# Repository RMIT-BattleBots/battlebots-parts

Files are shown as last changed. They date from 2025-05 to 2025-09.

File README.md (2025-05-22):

# BattleBots Club – 3D Printed Components Repository

Welcome to the official 3D components repository for the **RMIT BattleBots Club**! This repository contains all the STL, STEP, and source design files used in the construction and development of our robots' 3D printed parts.

## Repository Structure

```
battlebots-parts/
├── README.md
│
├── robot1_components/
│ ├── drivetrain/
│ │ ├── motor_mount.stl
│ │ ├── motor_mount.step
│ │ └── README.md
│ │
│ ├── armor/
│ │ ├── front_plate_v1.stl
│ │ ├── front_plate_v2.stl
│ │ ├── front_plate_v3.stl
│ │ ├── front_plate_v4.stl
│ │ ├── front_plate_v4.step
│ │ └── README.md
│ │
│ ├── mounts/
│ │ ├── esc_holder
│ │ │ ├── esc_holder.stl
│ │ │ └── escHolder.png
│
├── robot2_components/
│ ├── drivetrain/
│ │ ├── motor_mount.stl
│ │ ├── motor_mount.step
│ │ └── README.md
```

Each folder contains:

- `.stl` files – ready to slice and print
- `.step` or native CAD files – for easy modifications
- `.png` for images of the part, either the 3d model or the part implemented onto the part (make filename oneword please)
- A README describing how and where the part is used, settings used for printing and the image embed

## Contributing

We encourage club members to contribute their designs and improvements! please checkout `CONTRIBUTING.md`

Please ensure you have the right to share any files uploaded, especially if they are used for competition bots.

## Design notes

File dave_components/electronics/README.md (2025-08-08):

# Electronics

Folder contains electronics parts for Dave.

## Part(s) locations
The motor PCBs are located on the motors, where the motor pins are slotted and soldered into the two larger offset pin through holes in the PCB. 

## Version 2 Notes
 - Motor PCB is to allow for strong and compact perpindicular electrical connections within the robot housing.
     - Track width is 2.0mm which is more than enough for a 1-  2Amps
 - Overall profile is smaller, with larger holes
 - Made in KiCad

## Version 1 Notes 
 - Motor PCB is to allow for strong and compact perpindicular electrical connections within the robot housing.
     - Track width is like 2 or 1.5mm which is more than enough for a 1-2Amps
     - The lower 4 through holes which are compatible with JST XH A connectors (standard 2.5mm spacing) 
 - Made in KiCad

## Images

Current components:

#### Version 2

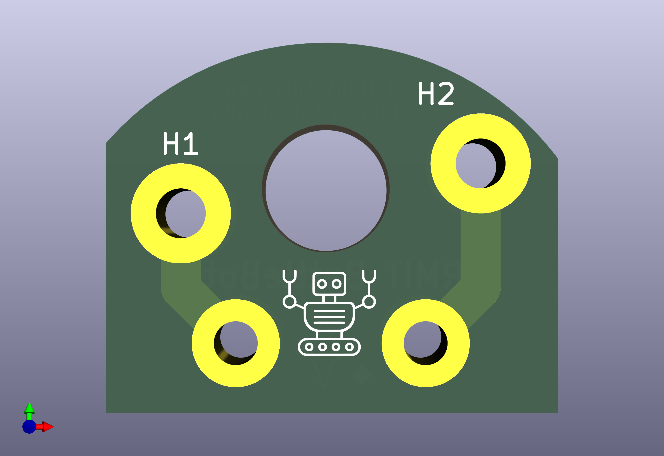
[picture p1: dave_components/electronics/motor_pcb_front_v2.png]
3D model top view of PCB


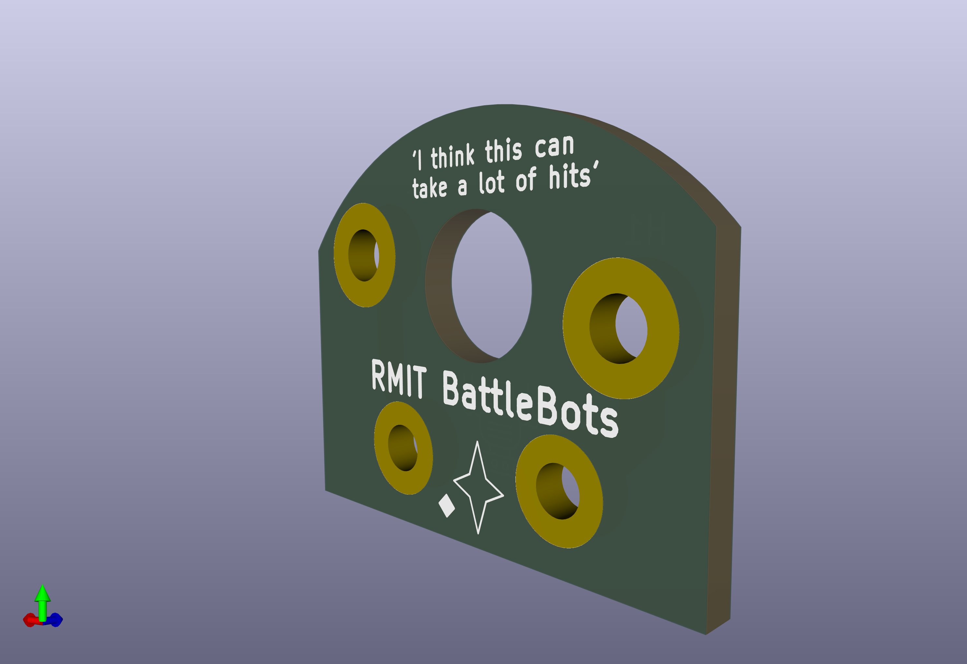
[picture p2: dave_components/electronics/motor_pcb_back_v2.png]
3D model back angled view of PCB


#### Version 1

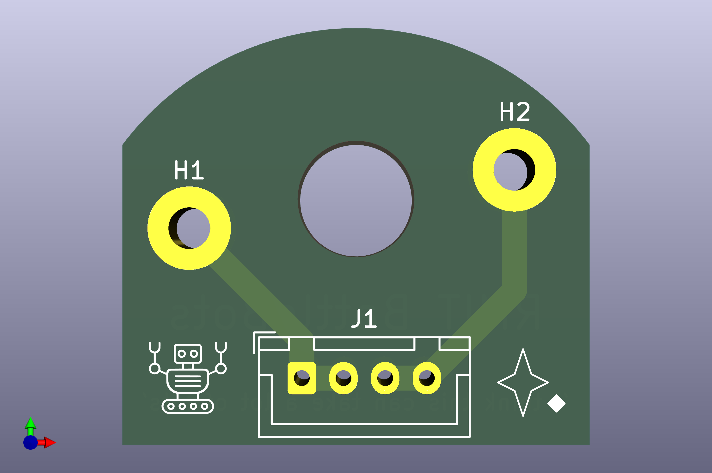
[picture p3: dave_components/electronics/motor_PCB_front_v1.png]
3D model top view of PCB 3D model top view of old PCB


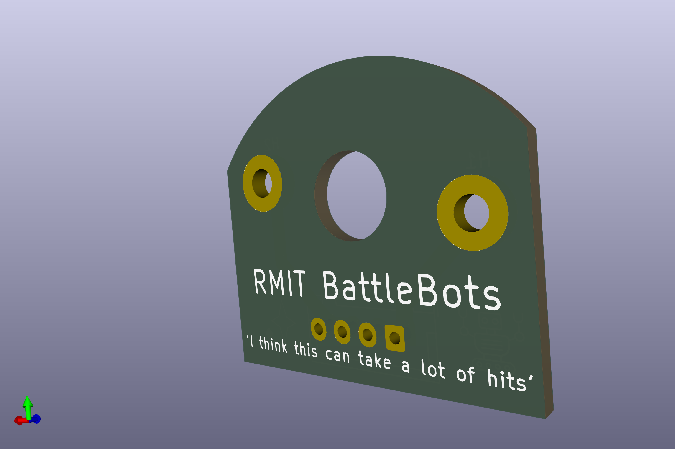
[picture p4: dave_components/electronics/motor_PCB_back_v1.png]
3D model back angled view of PCB 3D model back angled view of old PCB


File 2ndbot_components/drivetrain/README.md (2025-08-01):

# Drivetrain

Any and all parts related to the 2nd Bot drivetrain.

## Parts locations

The wheels are located to either side of the robot.

The motor brackets are connected to the base plate of the bot

## settings used for printing

- 30% infil
- default profile (0.2mm)

## Images

Current components:

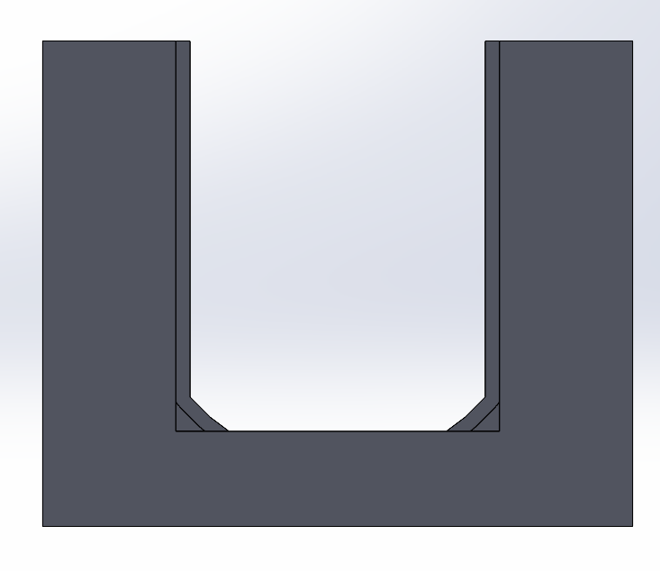
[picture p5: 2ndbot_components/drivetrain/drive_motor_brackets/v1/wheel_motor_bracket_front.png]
3D model of wheel motor bracket (front view)


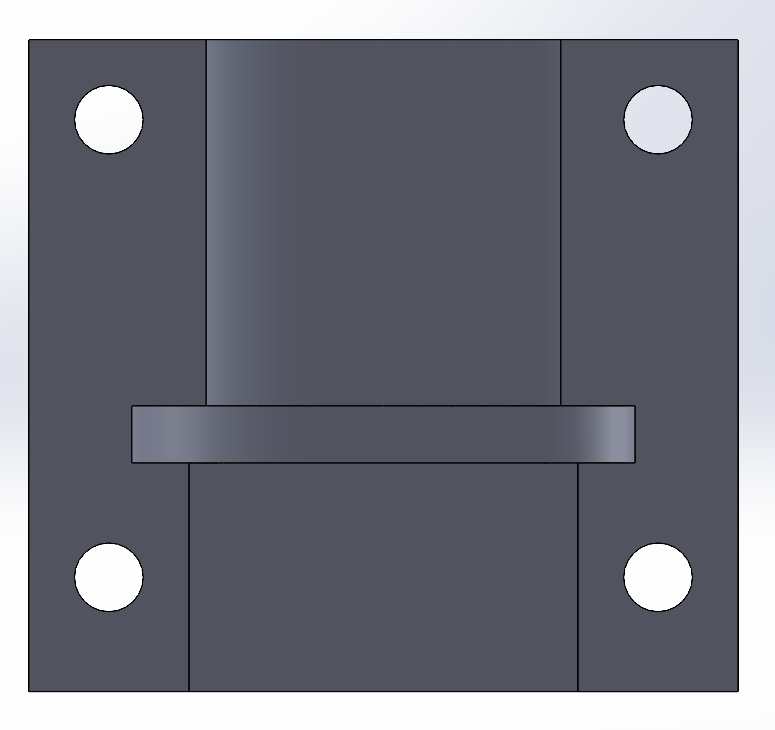
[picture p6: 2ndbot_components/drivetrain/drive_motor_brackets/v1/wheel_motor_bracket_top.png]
3D model of wheel motor bracket (top view)


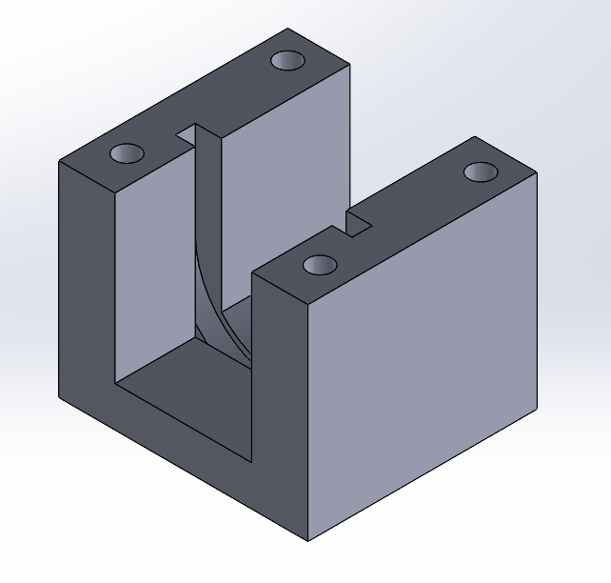
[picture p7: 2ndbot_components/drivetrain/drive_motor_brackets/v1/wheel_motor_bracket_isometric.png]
3D model of wheel motor bracket (isometric view)


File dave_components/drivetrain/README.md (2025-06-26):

# Drivetrain

Any and all parts related to the Dave drivetrain.

## Parts locations

The wheels are located to either side of the robot.

The motor brackets are located inside the robot housing adjacent to the wheels to hold the motors up. Version two has the mounts attach to the walls of the robot, whereas version one has a single pillar mounting to the floor of the robot

## settings used for printing

- 30% infil
- default profile (0.2mm)

## Images

Current components:

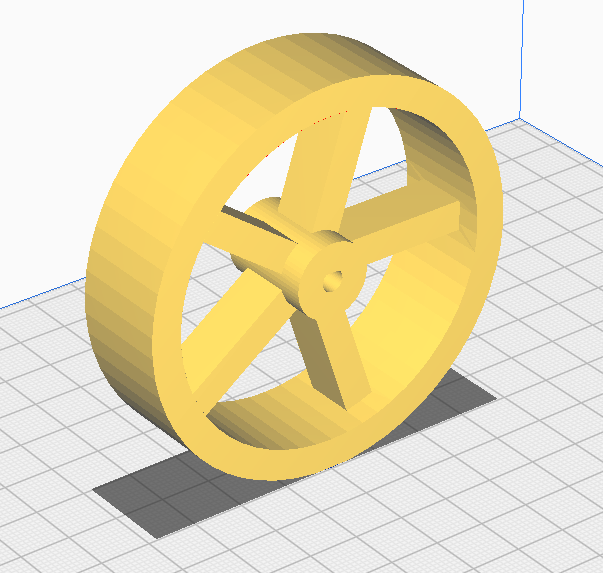
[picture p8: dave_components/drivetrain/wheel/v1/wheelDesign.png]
3D model of wheel design


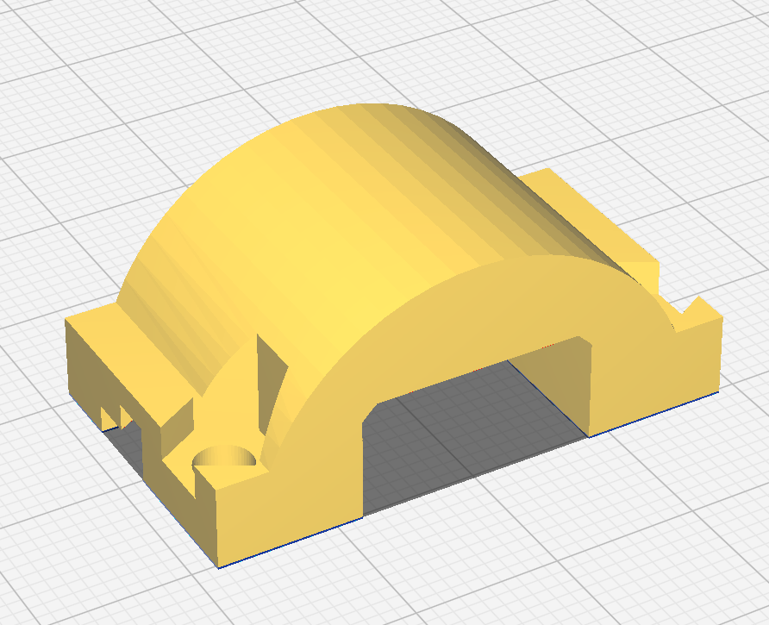
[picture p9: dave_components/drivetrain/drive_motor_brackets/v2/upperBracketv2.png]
3D model of upper bracket design


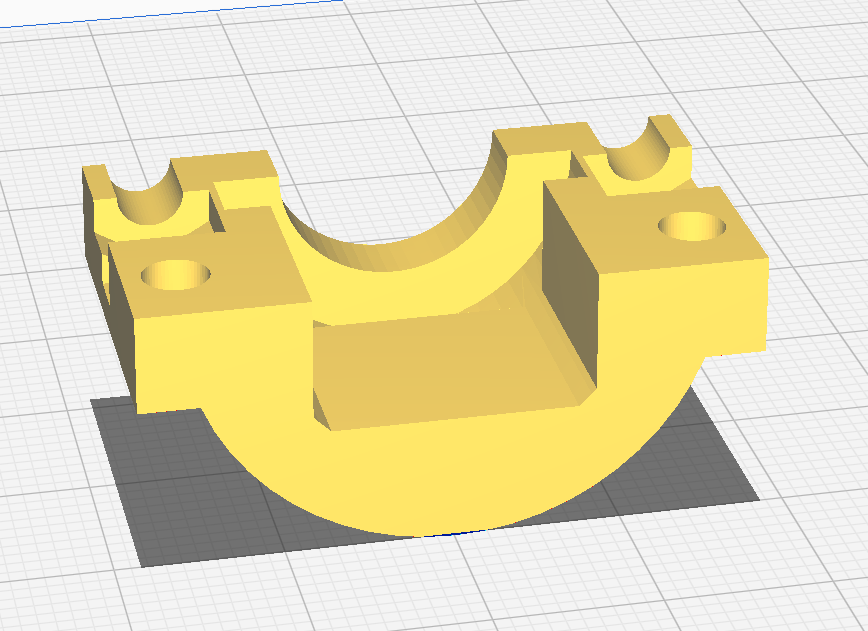
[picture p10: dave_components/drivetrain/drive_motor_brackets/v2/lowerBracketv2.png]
3D model of lower bracket design


Outdated/used prior:

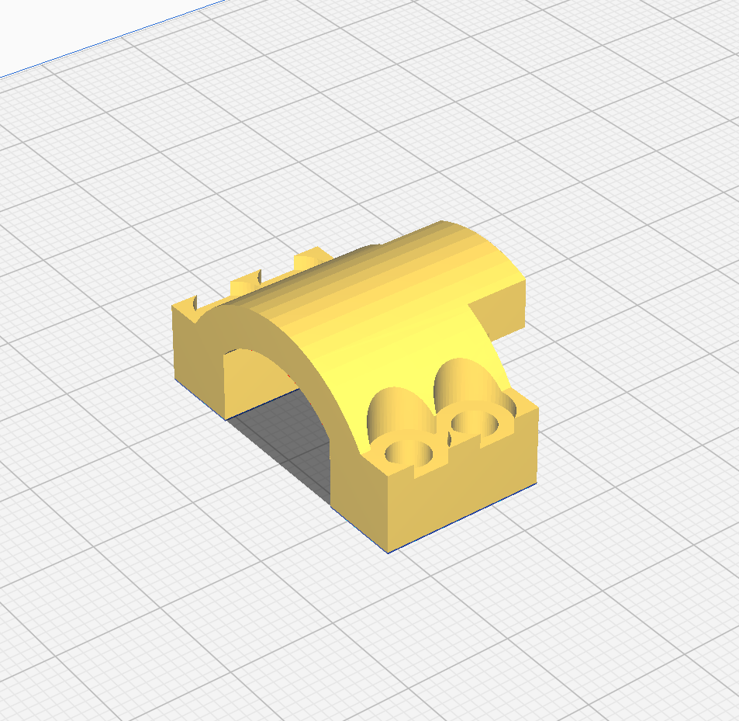
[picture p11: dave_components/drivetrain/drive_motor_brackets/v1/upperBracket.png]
3D model of old upper bracket design


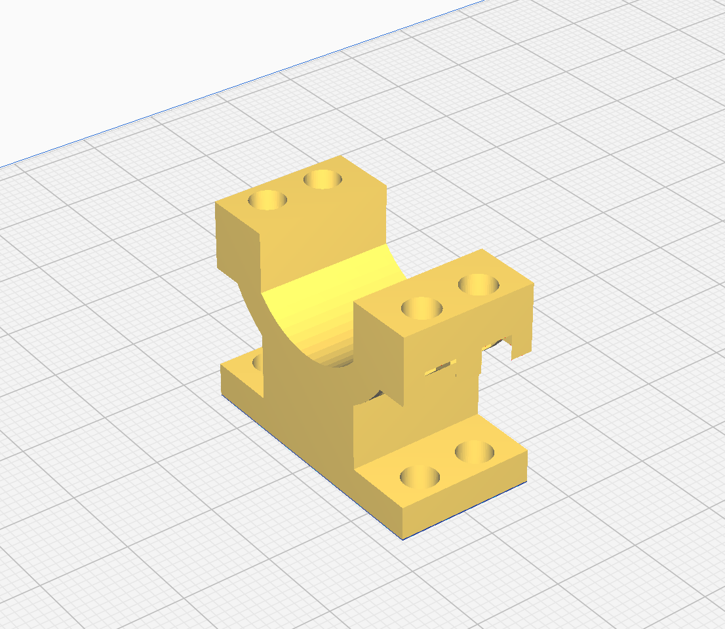
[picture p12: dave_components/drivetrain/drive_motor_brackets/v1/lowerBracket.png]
3D model of old lower bracket design


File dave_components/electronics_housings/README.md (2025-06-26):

# Electronics Housing

Any and all parts related to mounting electronics for Dave.

## Parts locations

The switch housing is located inside the housing towards the top side of the robot.

## settings used for printing

Infill negligible as the part is small enough to be mostly wall layers

## Images

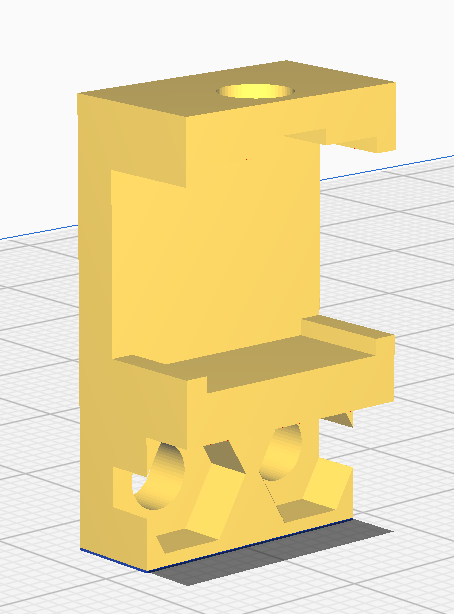
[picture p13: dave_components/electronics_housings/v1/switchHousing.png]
3D model of switch housing design


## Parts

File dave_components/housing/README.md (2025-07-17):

# Housing

Any and all parts related to the Dave housing/armour.

## Parts locations

The bracket is located in 4 instances, and uses bolts to fasten the side walls, roof and floor of the robot at each corner.

## settings used for printing

(?)

## Images

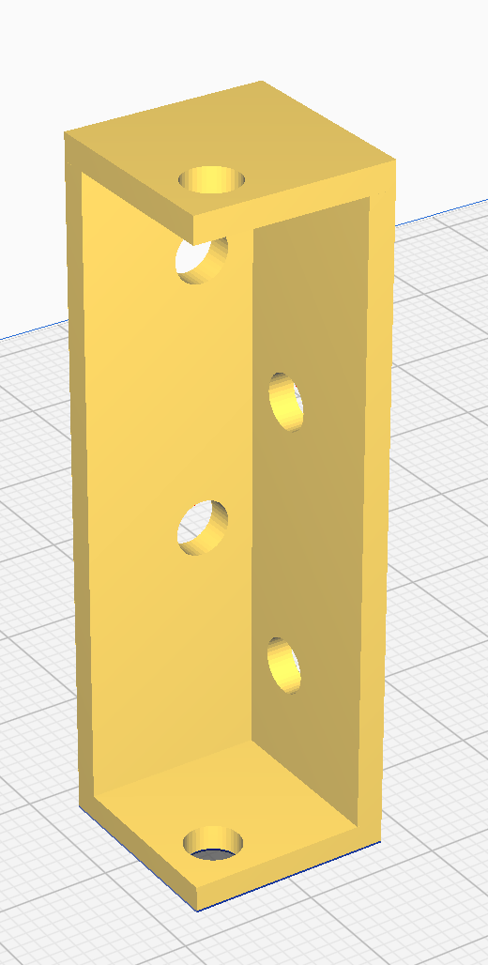
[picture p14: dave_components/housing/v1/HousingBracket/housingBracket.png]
3D model of housing bracket design


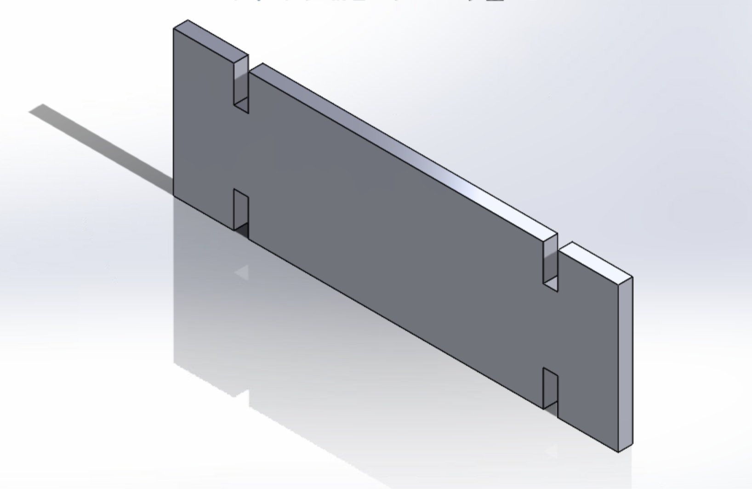
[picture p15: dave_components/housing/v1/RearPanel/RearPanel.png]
3D model of rear panel design


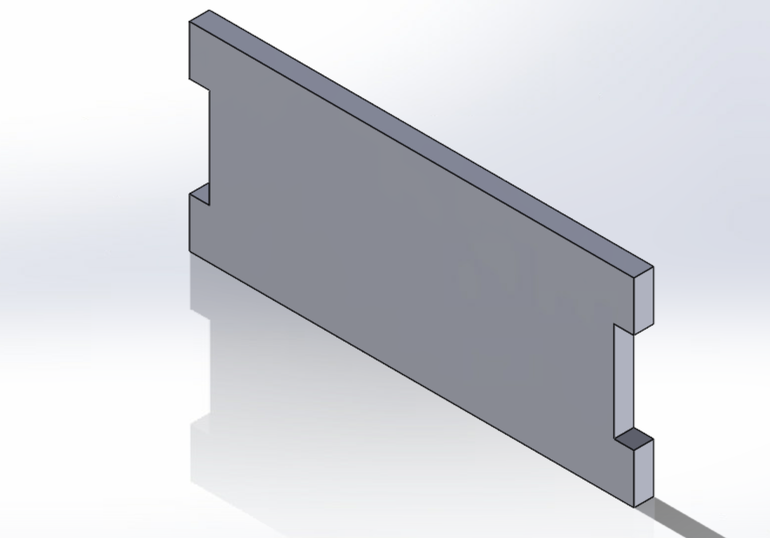
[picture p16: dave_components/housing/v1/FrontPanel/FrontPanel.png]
3D model of front panel design


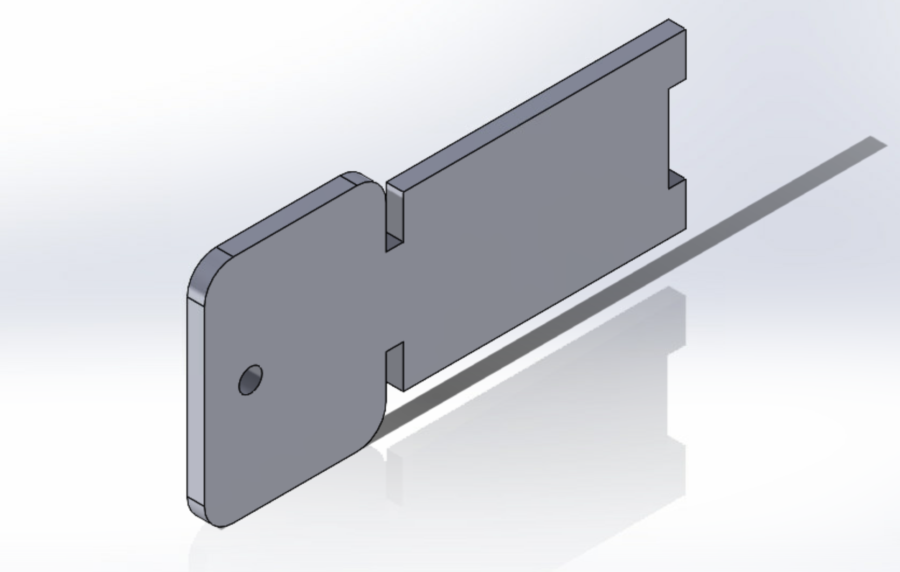
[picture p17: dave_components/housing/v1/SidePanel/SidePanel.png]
3D model of side panel design


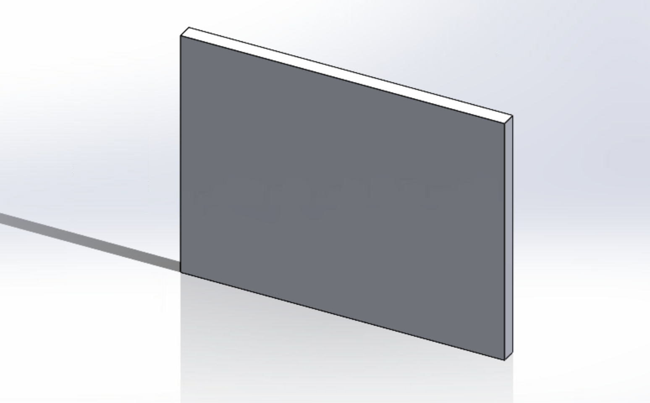
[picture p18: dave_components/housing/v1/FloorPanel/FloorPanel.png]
3D model of floor and roof panel design


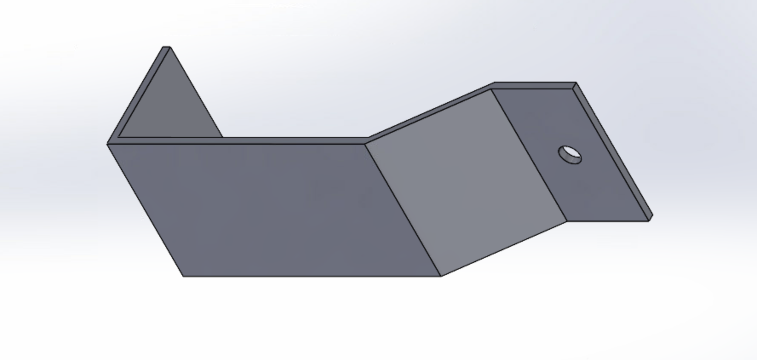
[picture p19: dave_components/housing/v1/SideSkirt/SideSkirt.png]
3D model of side skirt/shroud design


# V2 Housing

## Images

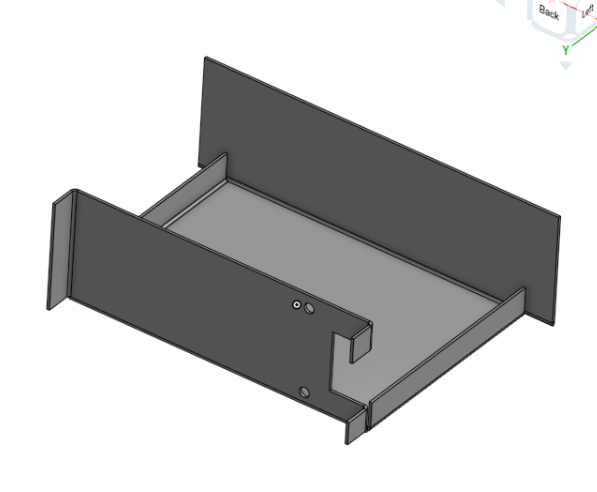
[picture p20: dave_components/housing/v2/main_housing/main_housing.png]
3D model of housing for electronics


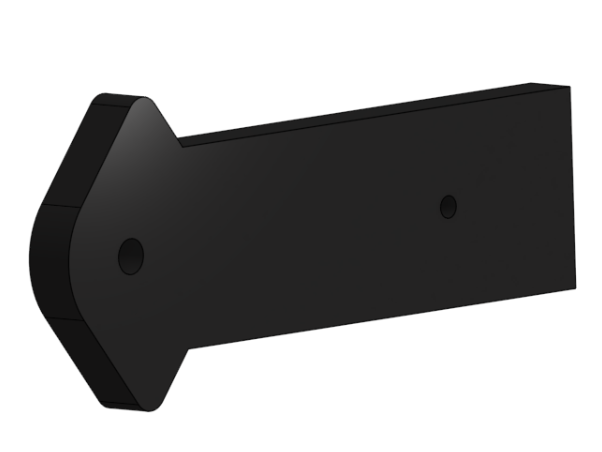
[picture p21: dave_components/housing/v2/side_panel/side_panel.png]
3D model of the side panel


3D model of the top and bottom structural plate

3D model of the wheel guard

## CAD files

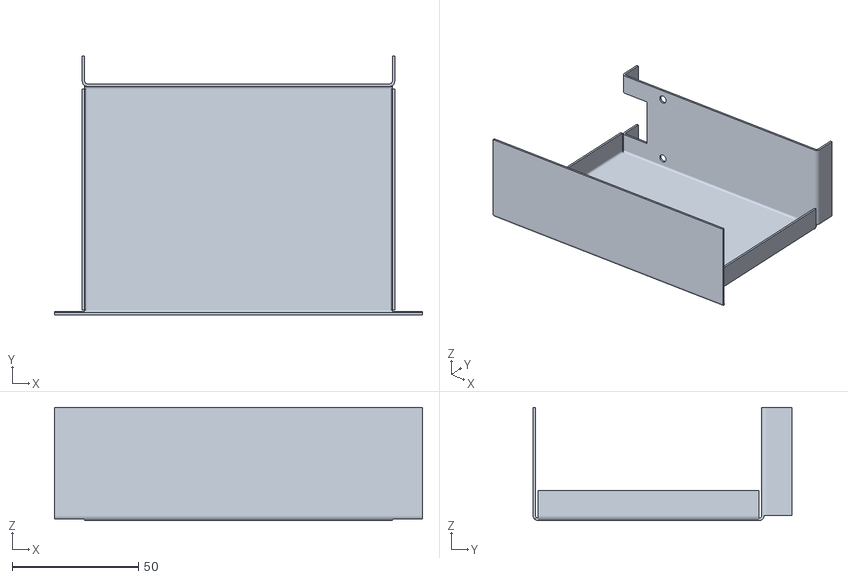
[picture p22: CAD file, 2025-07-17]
dave_components/housing/v2/main_housing/main_housing.stl
146.0 x 102.7 x 44.9

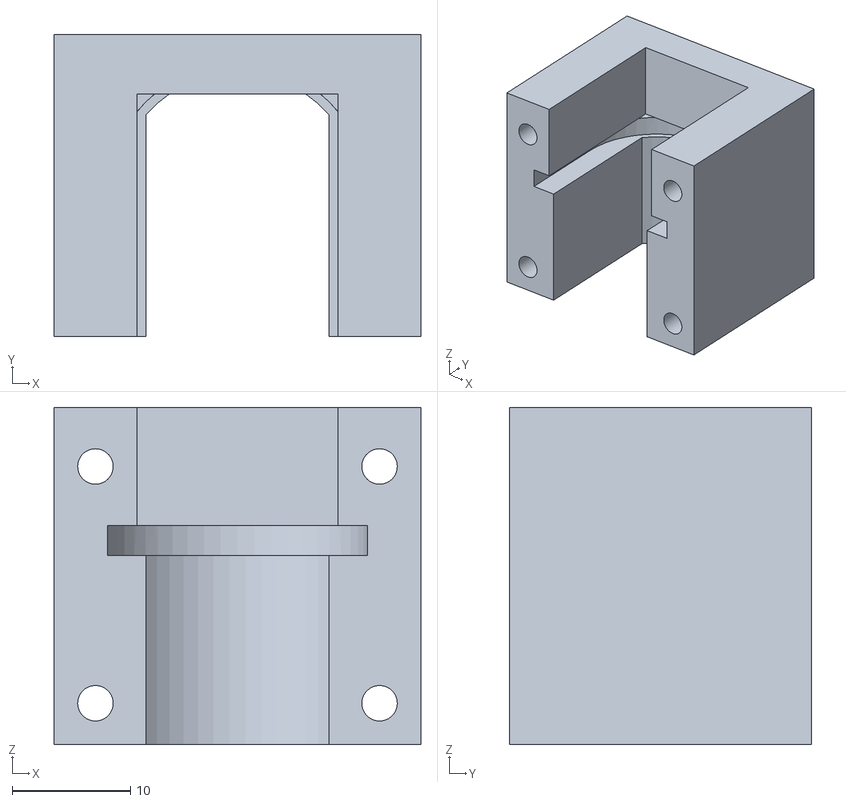
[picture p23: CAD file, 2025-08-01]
2ndbot_components/drivetrain/drive_motor_brackets/v1/Wheel_Motor_Bracket _V1.STL
31.0 x 25.5 x 28.5

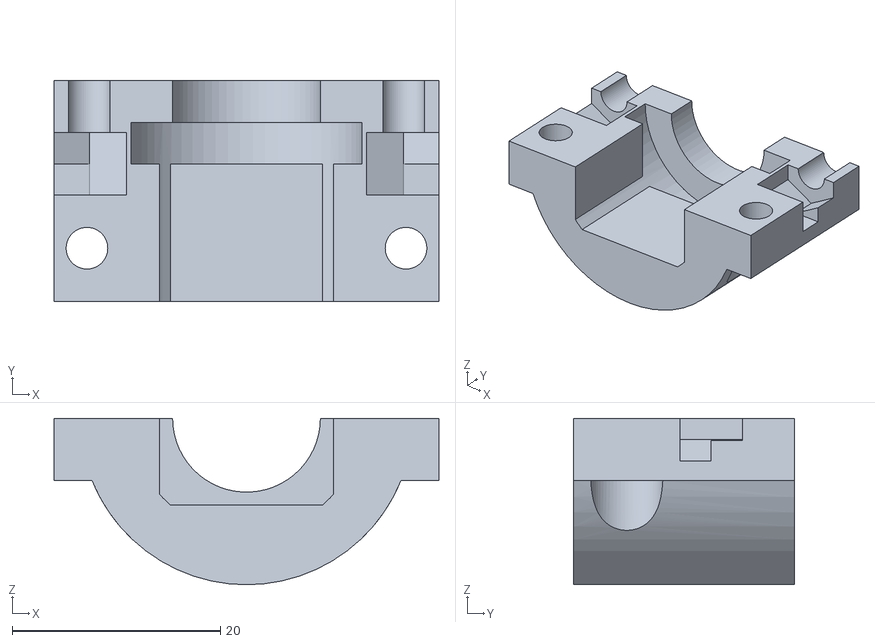
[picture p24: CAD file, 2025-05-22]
dave_components/drivetrain/drive_motor_brackets/v2/Drive2_Upper.stl
37.0 x 21.2 x 16.0

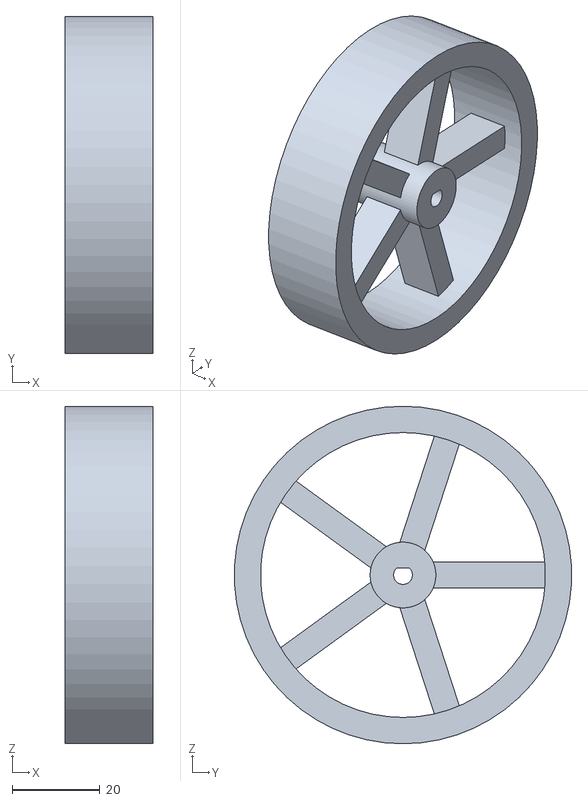
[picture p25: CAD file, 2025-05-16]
dave_components/drivetrain/wheel/v1/WheelDesign - Wheel v4.stl
20.0 x 76.9 x 77.0

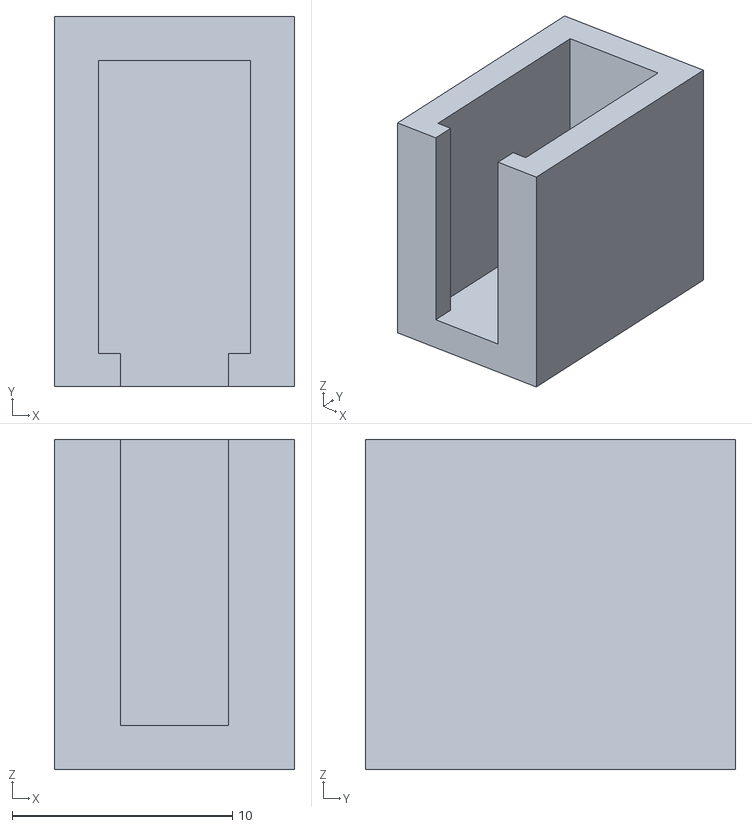
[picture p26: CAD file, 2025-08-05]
dave_components/electronics_housings/v2/Switch Housing.stl
10.9 x 16.8 x 15.0

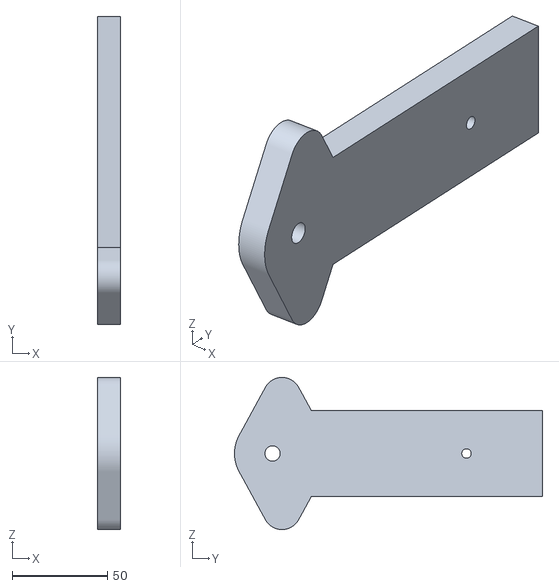
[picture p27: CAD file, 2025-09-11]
dave_components/housing/v2/side_panel/side_panel.stl
12.0 x 162.0 x 80.0

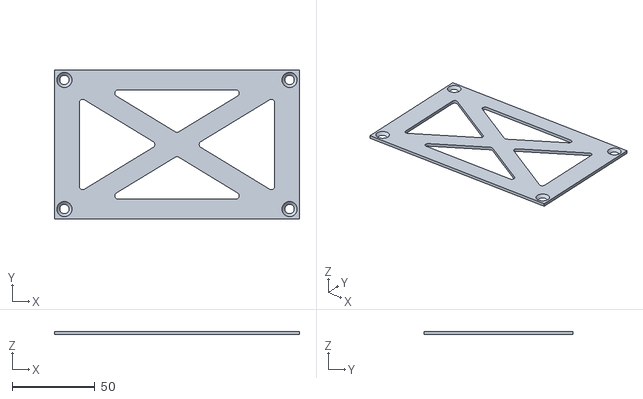
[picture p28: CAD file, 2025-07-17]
dave_components/housing/v2/top&bottom_plate/top&bottom_plate.stl
148.0 x 90.0 x 2.00

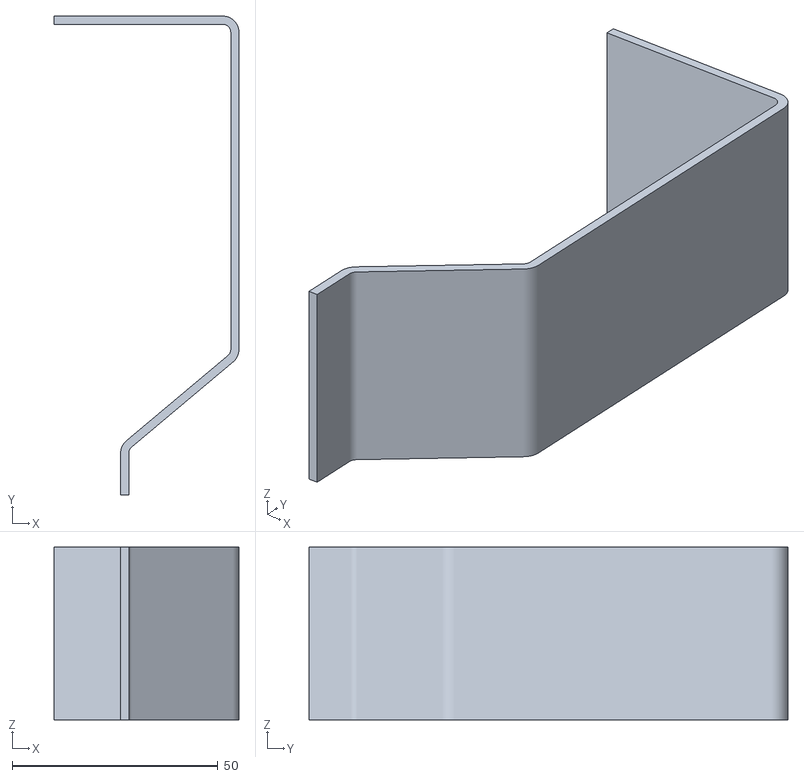
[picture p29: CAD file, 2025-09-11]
dave_components/housing/v2/wheel_guard/wheel_guard.stl
45.0 x 116.5 x 42.0

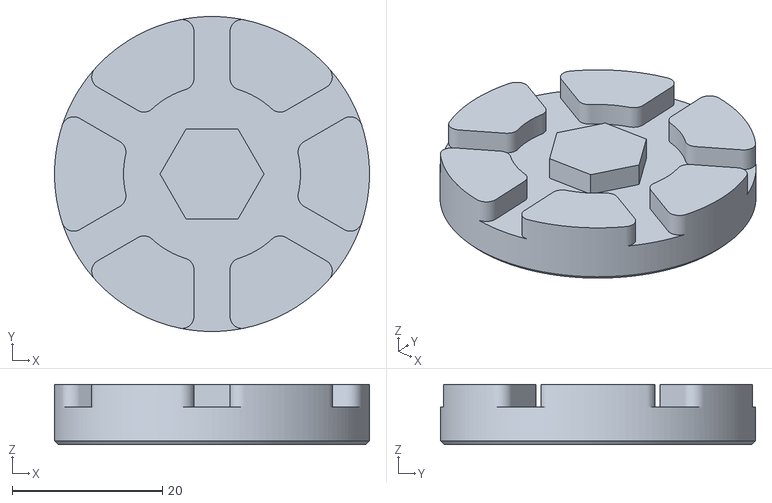
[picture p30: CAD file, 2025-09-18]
dave_components/wheel_mould/Inner.stl
42.0 x 42.0 x 8.00

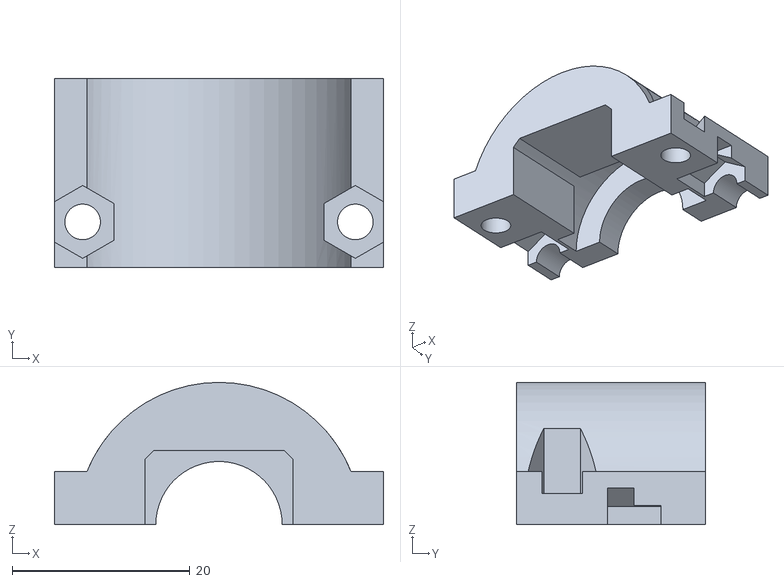
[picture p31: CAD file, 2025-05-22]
dave_components/drivetrain/drive_motor_brackets/v2/Drive2_Lower.stl
37.0 x 21.2 x 16.0

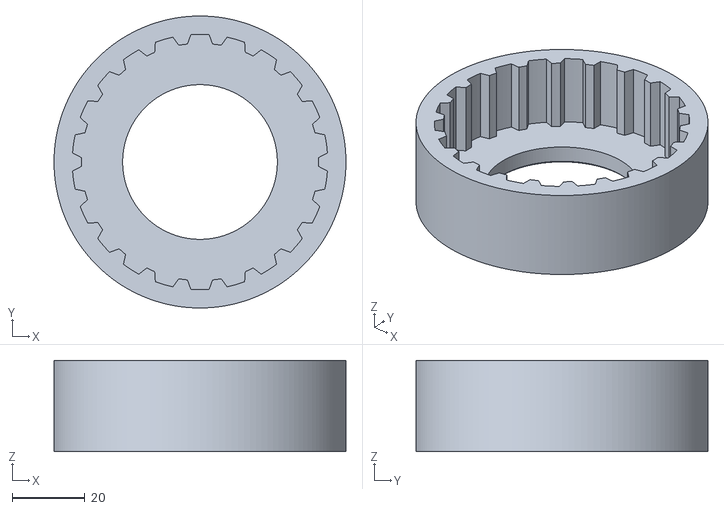
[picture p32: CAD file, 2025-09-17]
dave_components/wheel_mould/Outer.stl
80.0 x 80.0 x 25.0

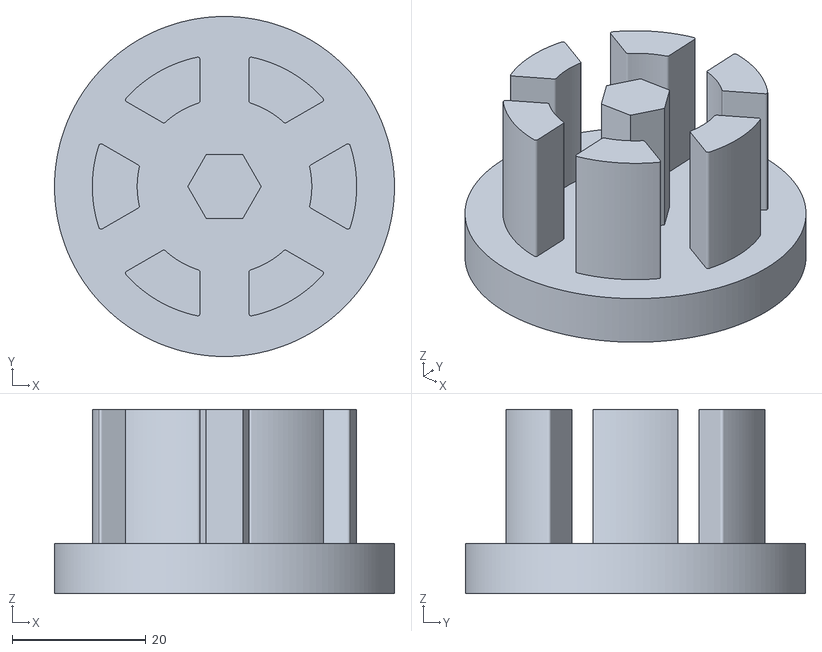
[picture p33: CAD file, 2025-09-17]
dave_components/wheel_mould/Remover.stl
50.8 x 50.8 x 27.5

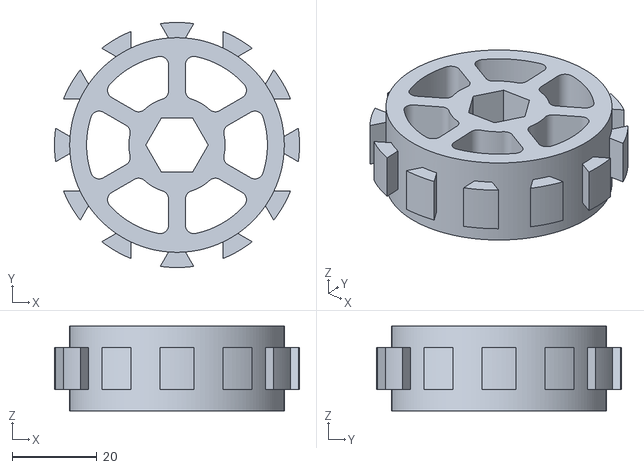
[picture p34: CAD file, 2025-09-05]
dave_components/wheel_mould/HUB2 mk2.stl
58.0 x 58.0 x 20.0

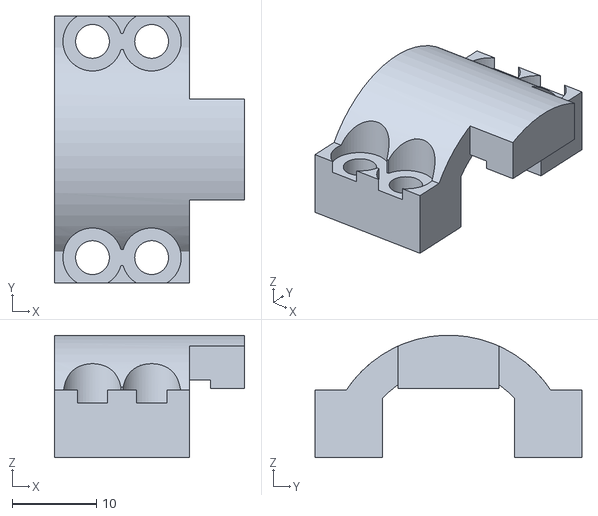
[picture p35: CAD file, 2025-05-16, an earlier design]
dave_components/drivetrain/drive_motor_brackets/v1/DriveBracket - UPPER.stl
22.5 x 31.6 x 14.5

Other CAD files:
dave_components/electronics_housings/v1/Switch housing - Part 1.stl
dave_components/housing/v1/FloorPanel/DaveFloorPanel.STEP
dave_components/housing/v1/FrontPanel/DaveFrontPanel.STEP
dave_components/housing/v1/HousingBracket/Bracket BB v3.stl
dave_components/drivetrain/drive_motor_brackets/v1/DriveBracket - LOWER.stl
dave_components/housing/v1/RearPanel/DaveRearPanel.STEP
dave_components/housing/v1/SidePanel/DaveSidePanel.STEP
dave_components/housing/v1/SideSkirt/DaveSideSkirt.STEP

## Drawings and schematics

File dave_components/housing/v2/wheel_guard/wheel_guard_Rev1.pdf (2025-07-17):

2
1

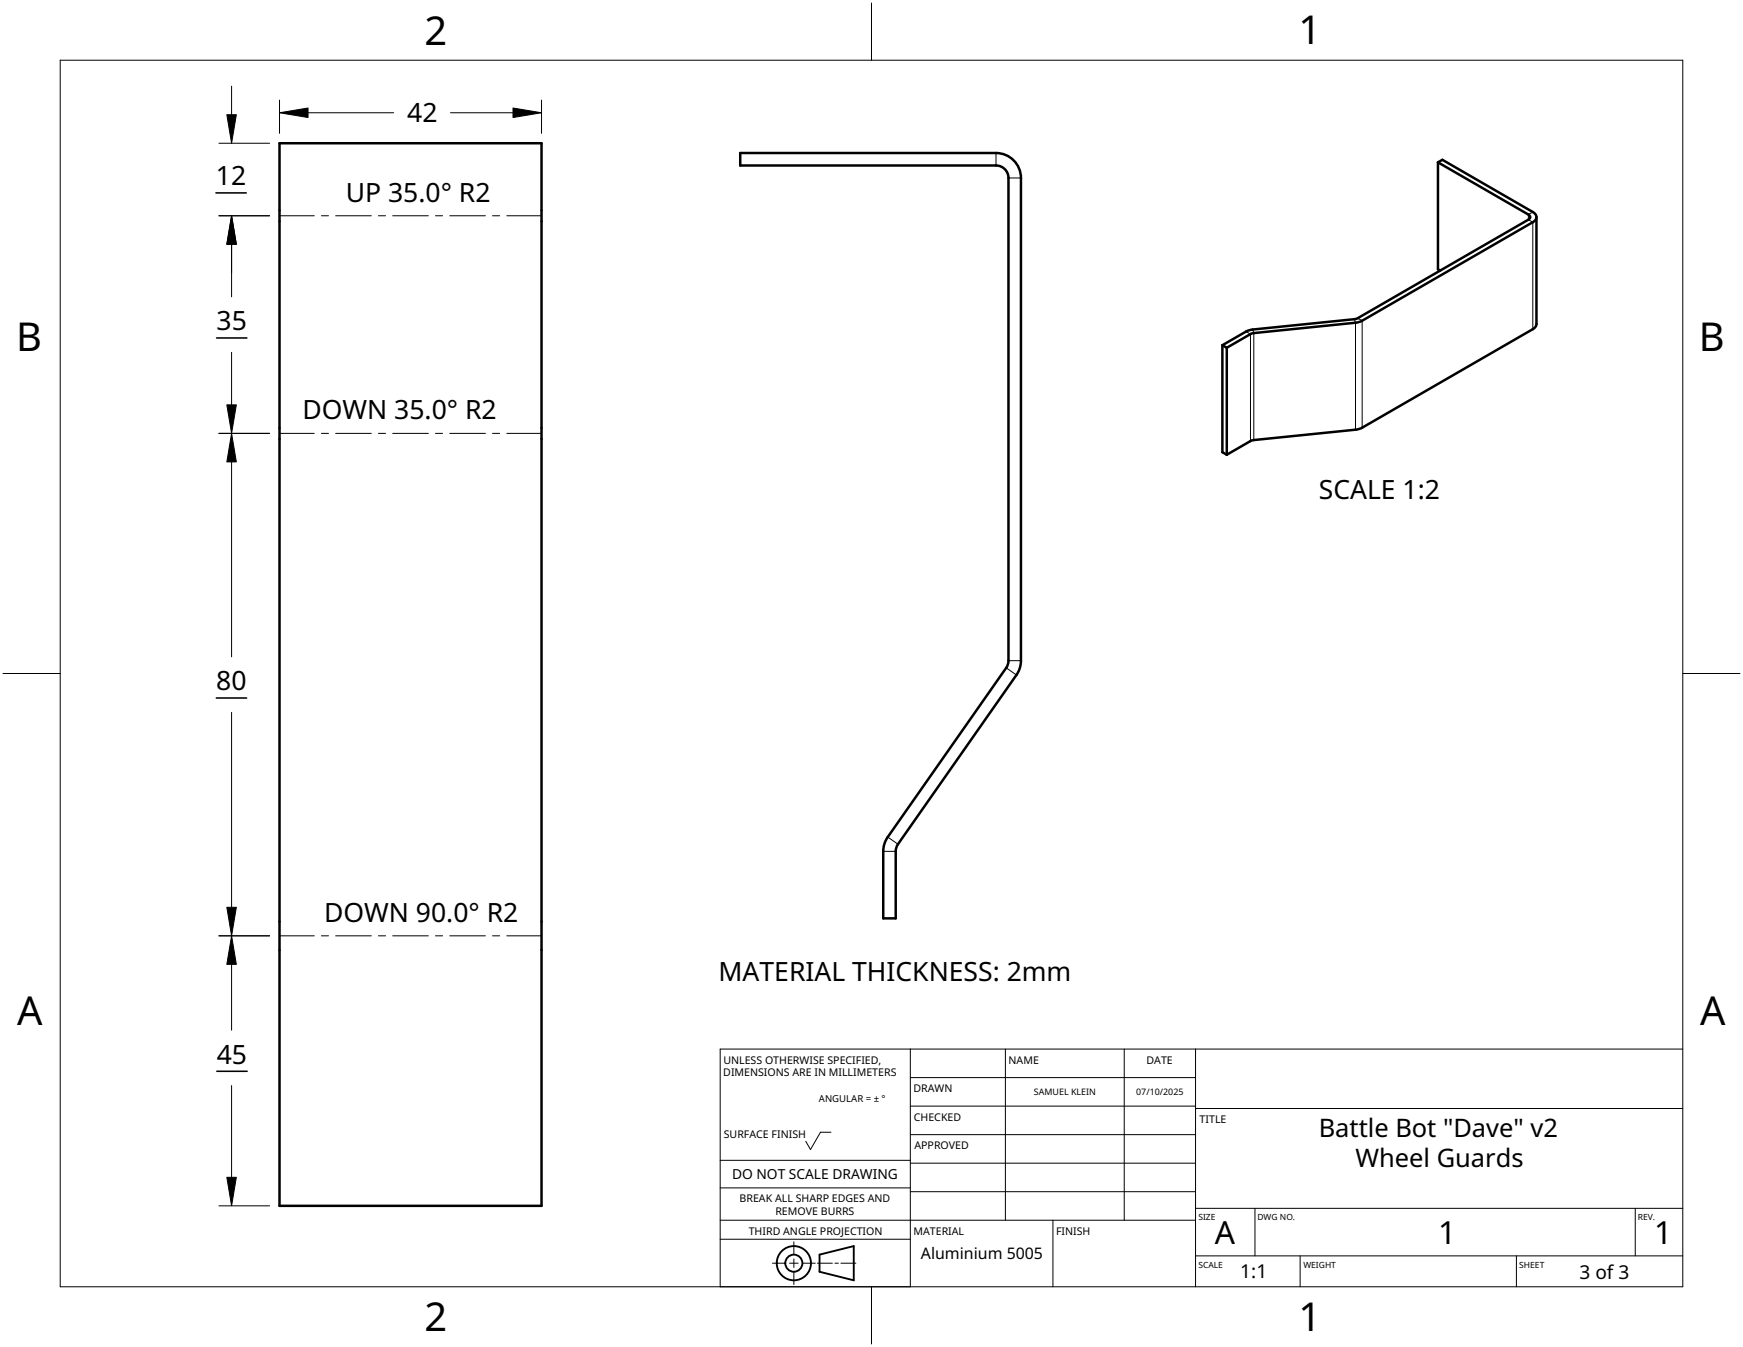
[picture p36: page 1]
MATERIAL Aluminium 5005; FINISH; DOWN 35.0° R2; DOWN 90.0° R2; MATERIAL THICKNESS: 2mm; SCALE 1:2

UNLESS OTHERWISE SPECIFIED, DIMENSIONS ARE IN MILLIMETERS ANGULAR = ± ° SURFACE FINISH | | NAME | DATE

DRAWN | SAMUEL KLEIN | 07/10/2025

CHECKED | | | TITLE Battle Bot "Dave" v2 Wheel Guards

APPROVED

DO NOT SCALE DRAWING

BREAK ALL SHARP EDGES AND

REMOVE BURRS
THIRD ANGLE PROJECTION

SIZE A | DWG NO. 1 | REV. 1

SCALE 1:1 | WEIGHT | SHEET 3 of 3

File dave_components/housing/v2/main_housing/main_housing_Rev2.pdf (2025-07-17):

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

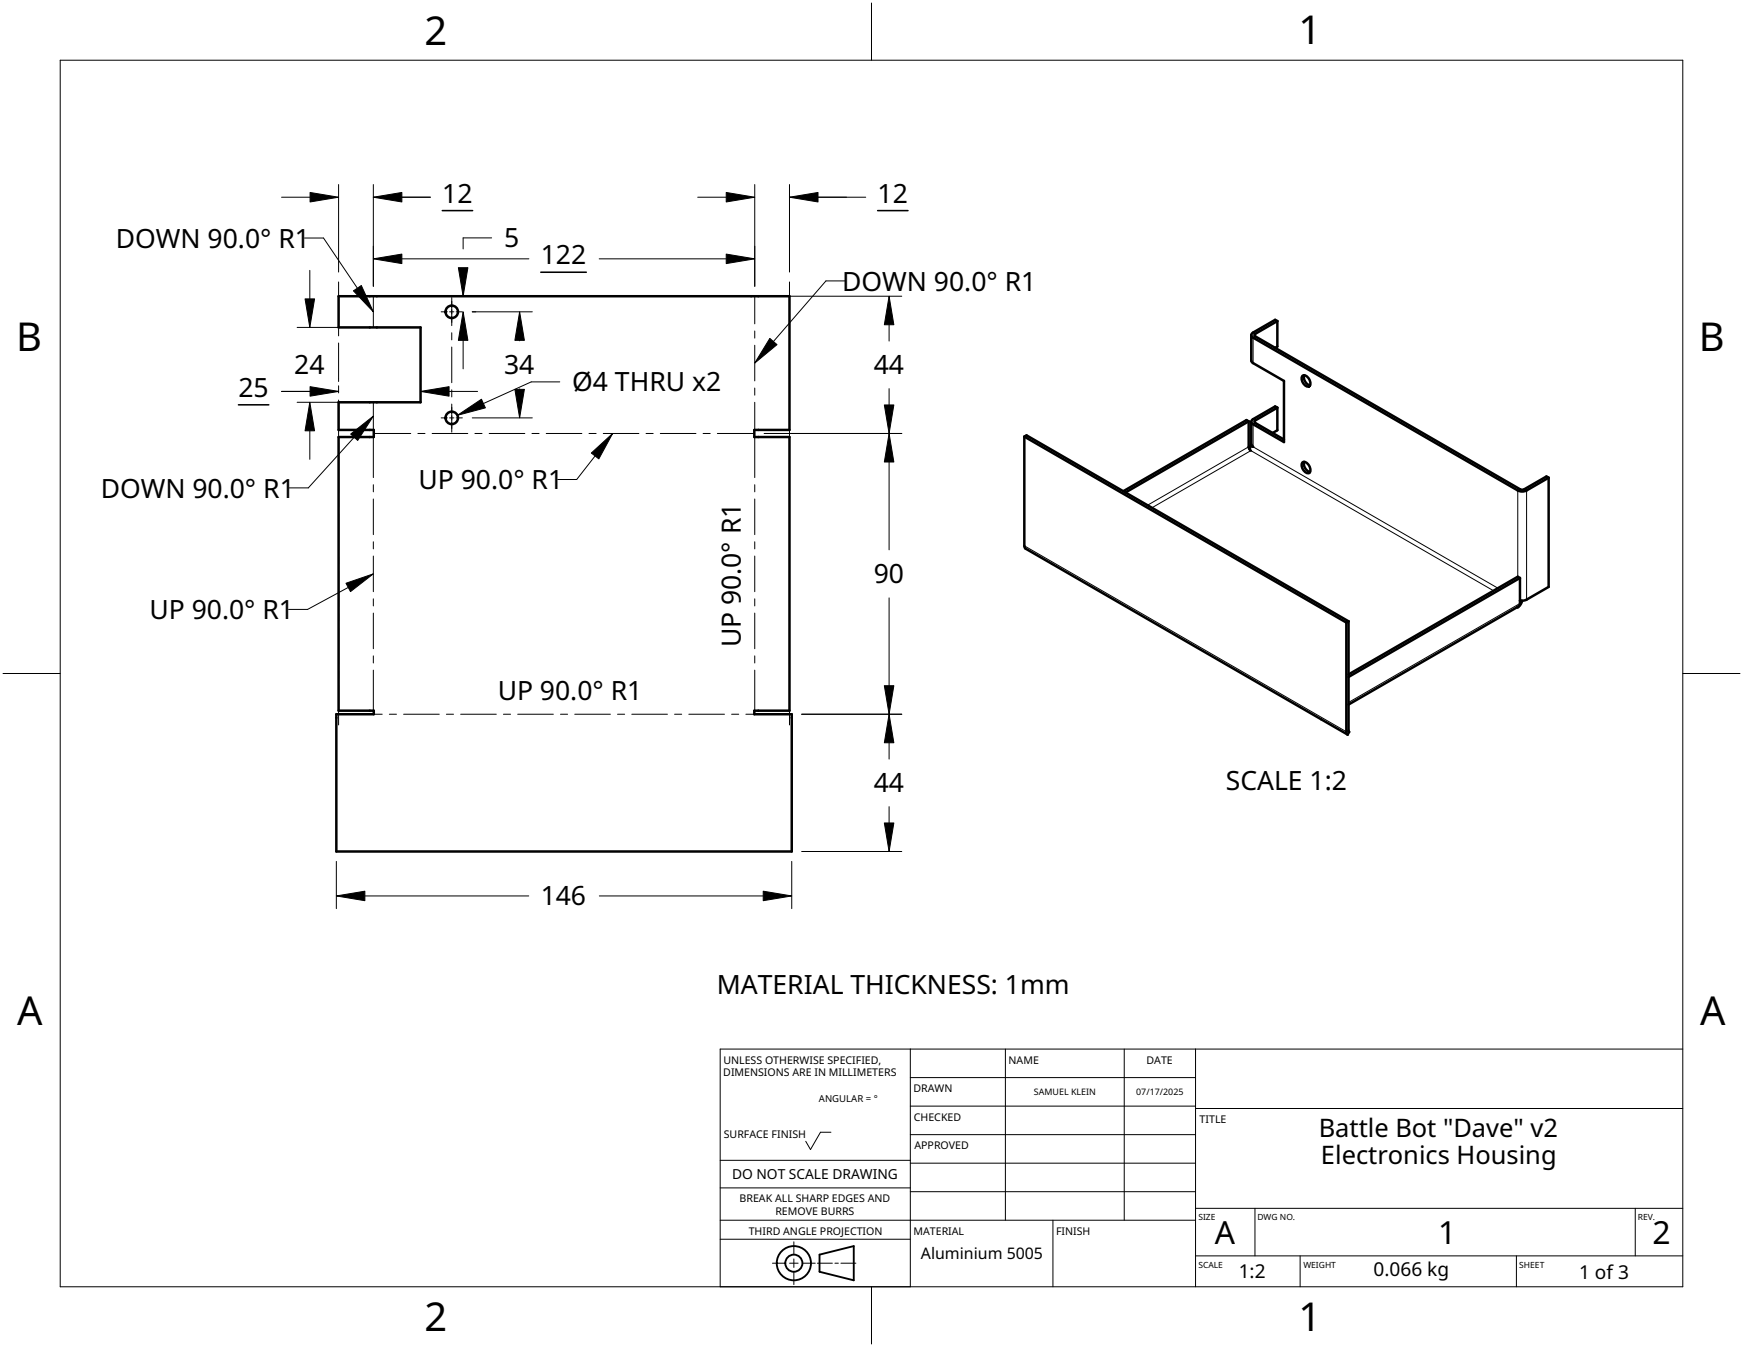
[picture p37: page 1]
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

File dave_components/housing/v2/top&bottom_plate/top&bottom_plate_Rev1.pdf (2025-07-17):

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

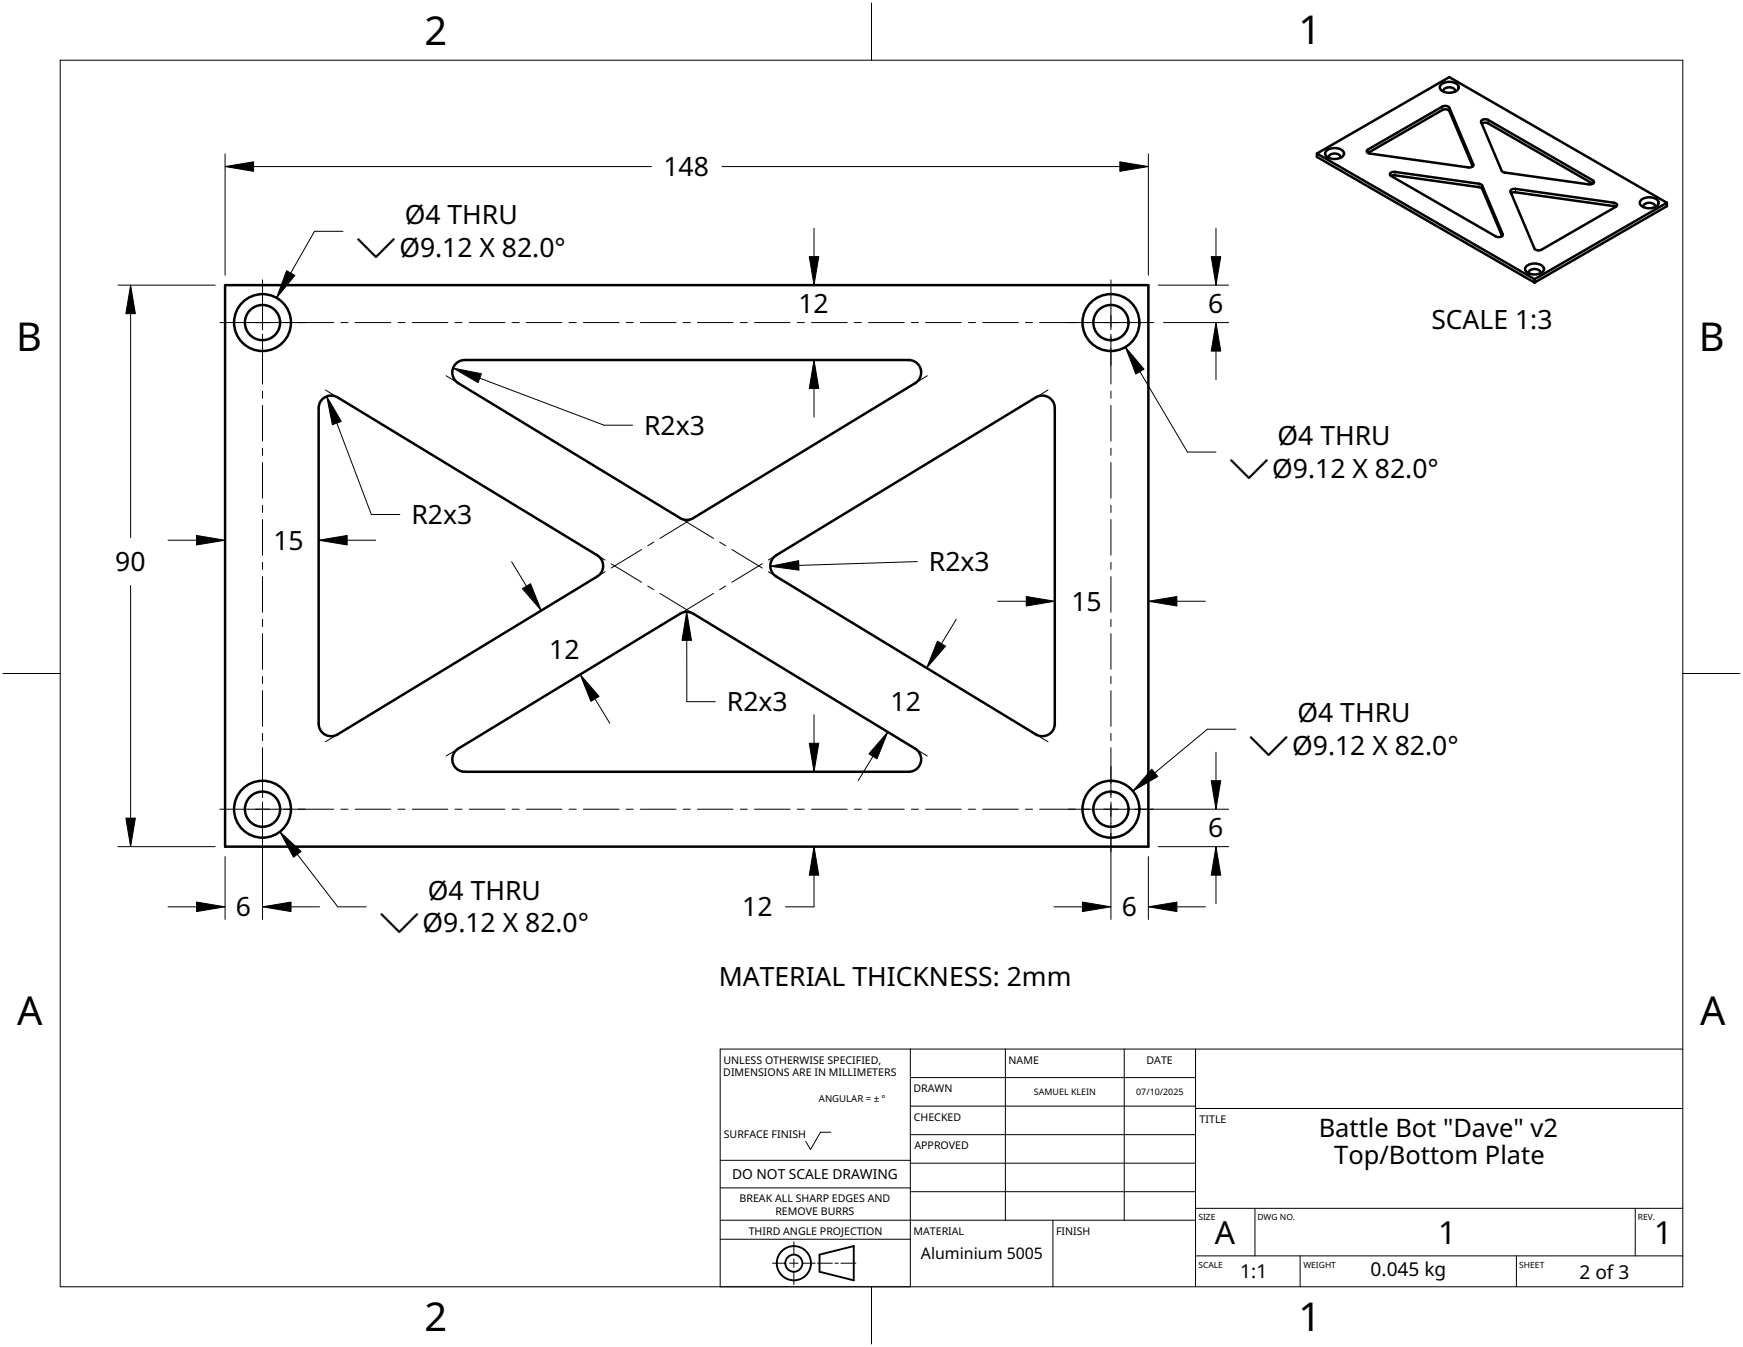
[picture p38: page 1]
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

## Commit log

2025-05-09 added current cad
    [Bracket BB v3.stl, DriveBracket - LOWER.stl, DriveBracket - UPPER.stl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]
2025-05-15 moving and nesting files
    [Bracket BB v3.stl, DriveBracket - LOWER.stl, DriveBracket - UPPER.stl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]
2025-05-16 wheel img fix
2025-05-16 add V2 for motor brackets, updated README
    [Drive2_Lower.stl, Drive2_Upper.stl, DriveBracket - LOWER.stl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]
2025-06-12 adding housing step files
    [Bracket BB v3.stl, DaveFloorPanel.STEP, DaveFrontPanel.STEP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]
2025-06-26 Add versions to the components
    [Bracket BB v3.stl, DaveFloorPanel.STEP, DaveFrontPanel.STEP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]
2025-07-17 V2 parts added
    Dave v2 parts added including:
    - stl's
    - png's
    - technical sheets
    v1 parts reorganized to accommodate v2 parts section.
    [Bracket BB v3.stl, DaveFloorPanel.STEP, DaveFrontPanel.STEP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]
2025-07-17 uploading gbr files for motor pcb
    [motorMount-B_Cu.gbr, motorMount-B_Mask.gbr, motorMount-B_Paste.gbr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]
2025-07-22 add lower through holes to design
    [motorMount-B_Cu.gbr, motorMount-B_Mask.gbr, motorMount-B_Paste.gbr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]
2025-07-24 add wheel mould
    [wheel_core.stl, wheel_mould.stl]
2025-08-01 Wheel motor bracket for the 2nd bot
    [Wheel_Motor_Bracket _V1.STL]
2025-08-05 added switch housing v2 (#13)
    [Switch Housing.stl]
2025-08-07 added PCB version 2 that fixes terminal spacing
    [motorMount-B_Cu.gbr, motorMount-B_Mask.gbr, motorMount-B_Paste.gbr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]
2025-08-21 Second design for wheel mould with removable base
    [wheel_mould.stl]
2025-09-05 update wheel core model
    [wheel_core.stl]
2025-09-05 add new hubs
    [HUB2 mk2.stl]
2025-09-11 udating side_panel and wheel_guard stl's
    [side_panel.stl, wheel_guard.stl]
2025-09-11 Feature/wheel v6 (#19)
    * {COMMIT MESSAGE}
    * {COMMIT MESSAGE}
    [Inner.stl, Outer.stl, wheel_core.stl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]
2025-09-17 {COMMIT MESSAGE} (#20)
    [Inner.stl, Outer.stl, Remover.stl]
2025-09-18 {COMMIT MESSAGE} (#22)
    [Inner.stl]
2025-10-02 Add drive system gears stl
